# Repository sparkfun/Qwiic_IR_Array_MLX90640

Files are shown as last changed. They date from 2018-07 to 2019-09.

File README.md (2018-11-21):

Qwiic IR Array (MLX90640)
==================

Qwiic IR Array

[*Qwiic IR Array (SEN-14843)*](https://www.sparkfun.com/products/14843)
[*Qwiic IR Array (SEN-14844)*](https://www.sparkfun.com/products/14843)

The MLX90640 contains a 32x24 array of thermopile sensors creating, in essence, a low resolution thermal imaging camera.

Repository Contents
-------------------
* **/Documentation** - Datasheets. 
* **/Firmware** - Examples to use the MLX90640 with a microcontroller.
* **/Hardware** - All Eagle design files (.brd, .sch). 
* **/Production** - Various test jigs and large panel layouts used for production.

Documentation
--------------
* **[Library](https://github.com/sparkfun/SparkFun_MLX90640_Arduino_Example)** - Arduino library for the Qwiic IR Array.
* **[Hookup Guide](https://learn.sparkfun.com/tutorials/qwiic-ir-array-mlx90640-hookup-guide)** - Basic hookup guide for the Qwiic IR Array.

Product Versions
----------------
* [SEN-14843](https://www.sparkfun.com/products/14843)- SparkFun 55 degree FOV
* [SEN-14844](https://www.sparkfun.com/products/14844)- SparkFun 110 degree FOV
* [SPX-14768](https://www.sparkfun.com/products/14768)- SparkX version

License Information
-------------------

The hardware is released under [Creative Commons ShareAlike 4.0 International](https://creativecommons.org/licenses/by-sa/4.0/).
The code is beerware; if you see me (or any other SparkFun employee) at the local, and you've found our code helpful, please buy us a round!

Distributed as-is; no warranty is given.

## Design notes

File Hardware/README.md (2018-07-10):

SparkFun <PRODUCT NAME> Design Files
=====================================

The .sch and .brd files hare are Eagle CAD schematic and PCB design files from SparkFun Electronics.
A freeware version of Eagle can be found [here](http://www.cadsoftusa.com/download-eagle/freeware/).

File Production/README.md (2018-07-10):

SparkFun <PRODUCT NAME> Production Files
=========================================

These are the production files SparkFun uses for printing PCBs.

License Information
-------------------
This product is open source! 

The hardware is released under [Creative Commons ShareAlike 4.0 International](https://creativecommons.org/licenses/by-sa/4.0/).

Please use, reuse, and modify these files as you see fit. Please maintain attribution to SparkFun Electronics and release anything derivative under the same license.

Distributed as-is; no warranty is given.

- Your friends at SparkFun.

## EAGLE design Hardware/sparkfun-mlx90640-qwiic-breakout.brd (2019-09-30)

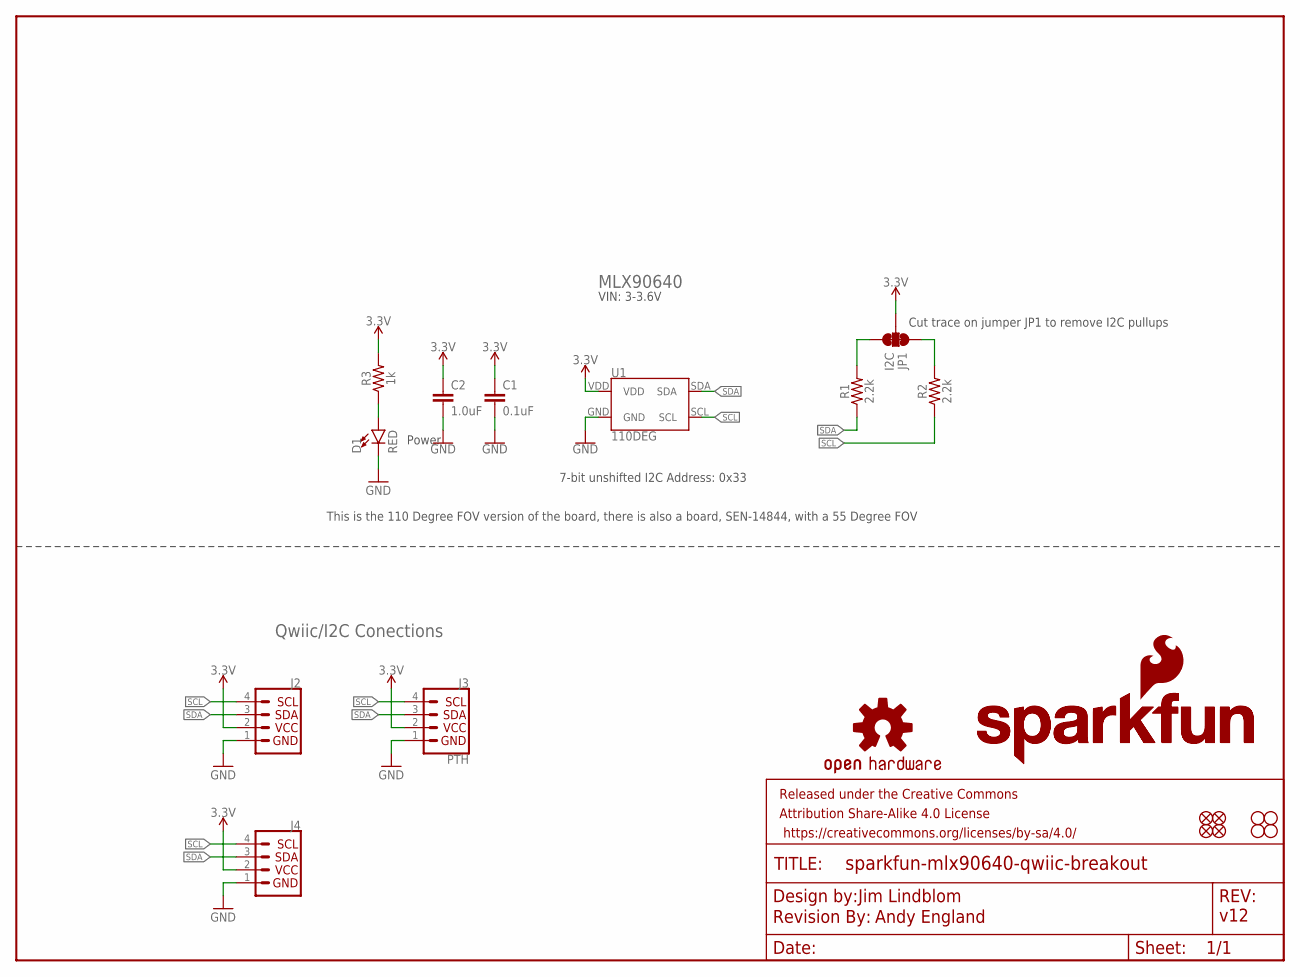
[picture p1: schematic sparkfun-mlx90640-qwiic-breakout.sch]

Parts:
C1: 0.1uF; 0603
C2: 1.0uF; 0603
D1: RED; LED-0603
FRAME1: FRAME-LETTER; CREATIVE_COMMONS
J2, J4: QWIIC_CONNECTORJS-1MM; JST04_1MM_RA
J3: PTH; 1X04_NO_SILK
JP1: I2C; SMT-JUMPER_3_2-NC_TRACE_NO-SILK
JP2, JP5, JP6, JP7: FIDUCIALUFIDUCIAL; MICRO-FIDUCIAL
JP3, JP4, JP8, JP9: STAND-OFF
LOGO1: OSHW-LOGOMINI; OSHW-LOGO-MINI
LOGO2: SFE_LOGO_NAME_FLAME.1_INCH; SFE_LOGO_NAME_FLAME_.1
LOGO3: SFE_LOGO_NAME.1_INCH; SFE_LOGO_NAME_.1
LOGO4: REVISION
R1, R2: 2.2k; 0603
R3: 1k; 0603
U1: 110DEG; MLX90540_MLX90640

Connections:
3.3V: C1.1, C2.1, J2.2, J3.2 (VCC), J4.2, JP1.2, R3.2, U1.VDD
GND: C1.2, C2.2, D1.C, J2.1, J3.1 (GND), J4.1, U1.GND
unnamed: JP1.3, R1.2
unnamed: JP1.1, R2.2
unnamed: D1.A, R3.1
SCL: J2.4, J3.4 (SCL), J4.4, R2.1, U1.SCL
SDA: J2.3, J3.3 (SDA), J4.3, R1.1, U1.SDA

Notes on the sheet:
Power
Jim Lindblom
7-bit unshifted I2C Address: 0x33
v12
Andy England
MLX90640
Qwiic/I2C Conections
VIN: 3-3.6V
This is the 110 Degree FOV version of the board, there is also a board, SEN-14844, with a 55 Degree FOV
Cut trace on jumper JP1 to remove I2C pullups

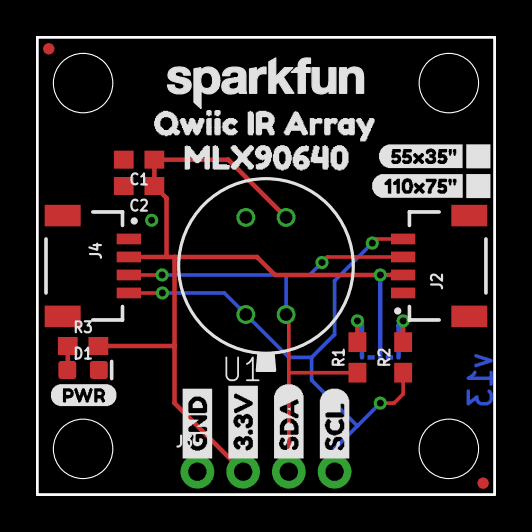
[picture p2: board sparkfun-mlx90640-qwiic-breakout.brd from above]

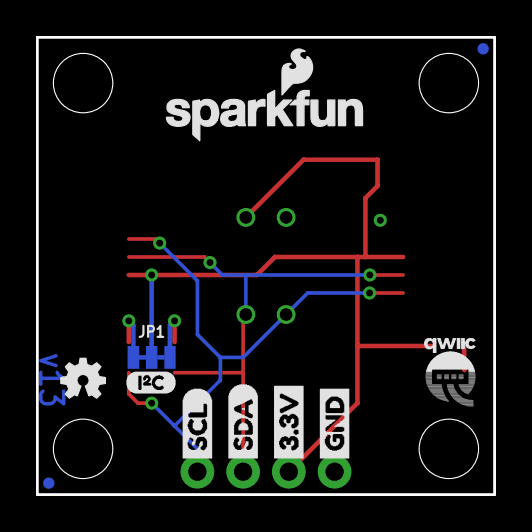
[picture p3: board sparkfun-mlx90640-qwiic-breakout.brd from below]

Board: 2 copper layers, 25.4 x 25.4 mm, 39 parts (11 on the bottom side), 7 nets.

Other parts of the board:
U$1, U$7: SDA-[)
U$3: 55X35#1
U$4, U$8: SCL-[)
U$5, U$9: 3.3V
U$6, U$10: GND-04
U$11: QWIIC-LOGO-SMALL
U$12: PWR-()-03
U$13: MLX906401
U$14: QWIIC_IR_ARRAY0
U$15: 110X75#0
U$16: I_SUPER2_C-()-03

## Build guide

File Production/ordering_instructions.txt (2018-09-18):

panel size, 221x143mm
PCB thickness, 1.6mm
number of layers, 2
soldermask color, Red
silkscreen color, White
oz copper, 1oz
finish, HASL lead free
stencils, none
pcs per panel, 40

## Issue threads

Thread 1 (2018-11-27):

Qwiic_IR_Array_MLX90640 not found by neither i2cdetect nor i2c mulitscanner

namoaton, 2018-11-27:
### Subject of the issue
Qwiic_IR_Array_MLX90640 not found by neither i2cdetect nor i2c mulitscanner
There is a situation when connect scl line on logic analyzer not signal and low level

### Your workbench
* What platform are you using?
raspberry pi 3, linux, and i2 scanner on arduino.
* What version of the device are you using? Is there a firmware version?
last version, which produced in october. wait it for 2 month and now have such problem
* How is the device wired to your platform?
with qwiic connector and directly to pins on rpi3
* How is everything being powered?
from 3.3v pin on rpi3
* Are there any additional details that may help us help you?
I try as with pull up resistors and without them
### Steps to reproduce
Tell us how to reproduce this issue. Please post stripped down example code demonstrating your issue to a gist.
In raspi-config enable i2c support. connect. try to run 'sudo i2cdetect -y 1' and nothing happens.

### Expected behaviour
Tell us what should happen
I expected to get found address 0x33 as described in  manual on Sparkfun site
### Actual behaviour
Tell us what happens instead
Nothing happens. I2cscanner freezes, logic anaylizer is silent, on rpi  silence.

AndyEngland521, 2018-11-27:
This is a small hardware issue that we currently have a fix on order for. The bottom plate of the MLX is ground and on occasion, Solder will flow onto this plate, connecting a signal to ground. My guess is that this is what happened on your SCL signal, and it slipped through our quality control. We have fixed our design to remedy this issue, but it will take a bit of time for this new design to arrive, but give our customer service a call at 1-303-284-0979

Closed 2018-11-27.

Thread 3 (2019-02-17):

"MLX90640 not detected at default I2C address. Please check wiring. Freezing."

ManiLowc, 2019-02-17:
### Subject of the issue
I've downloaded the example code and have been trying to get my sparkfun Qwiic IR Array MLX90640 to work but receive the above error. I have tried the i2c_scanner code to see if my Due was finding the array and it says that an I2C device was found.

When I run the i2c_scanner code my serial port gives:
Scanning...
I2C device found at address 0x0A  !
I2C device found at address 0x13  !
I2C device found at address 0x1A  !
I2C device found at address 0x22  !
I2C device found at address 0x28  !
I2C device found at address 0x2E  !
I2C device found at address 0x34  !
I2C device found at address 0x3A  !
I2C device found at address 0x40  !
I2C device found at address 0x44  !
I2C device found at address 0x48  !
I2C device found at address 0x4C  !
I2C device found at address 0x50  !
I2C device found at address 0x54  !
I2C device found at address 0x57  !
I2C device found at address 0x5B  !
I2C device found at address 0x5F  !
I2C device found at address 0x62  !
I2C device found at address 0x66  !
I2C device found at address 0x6A  !
I2C device found at address 0x6D  !
I2C device found at address 0x71  !
I2C device found at address 0x74  !
I2C device found at address 0x78  !
I2C device found at address 0x7C  !
done

### Your workbench
* What platform are you using?
I'm using the Arduino Due, Qwiic Shield (DEV-14352 ) and Qwiic IR Array MLX90640 (55x35).
* What version of the device are you using? Is there a firmware version?
I'm using the latest Arduino Due, purchased in November 2018. My 'boards manager' and 'library manager' are all up to date with the latest versions.
* How is the device wired to your platform?
I have connected the IR Array with a connector cable to the Qwiic Shield, which is pinned into the Arduino Due. I have the Shield connected to the Due such that A5, IRF, SCL, and RX on the board matches with the Arduino (SCL1 for the arduino) [I've tried attaching a picture as well to make it clearer]

* How is everything being powered?
I have connected the arduino to my pc to be powered.
* Are there any additional details that may help us help you?
I'm a complete novice so sorry for any useless information.

### Steps to reproduce
Tell us how to reproduce this issue. Please post stripped down example code demonstrating your issue to a gist.
I used the code on github, but for the first example I get the error of MLX not detected at default I2C address.

### Expected behaviour
Tell us what should happen
I was expecting the code to run and see values on the serial monitor.

### Actual behaviour
Tell us what happens instead
I get the error MLX90640 not detected at default I2C address.
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

Thank you in advance for any help and it is greatly appreciated!

nseidle, 2019-02-18:
Hi ManiLowc,

I recommend against using a Due. It's I2C implementation has been giving us problems with the ML90640. See this [issue](https://github.com/sparkfun/SparkFun_MLX90640_Arduino_Example/issues/1).

Second possible source of problems: We've had two revisions of this product. If you have the first revision, you may be running into a hardware issue. Can you please post a picture of your MLX90640?

For reference, on the 2nd rev of the board the tab on the sensor has been re-aligned to better line up the pixels of the frame to the orthagonal orientation of the board.

This is rev one:

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

ManiLowc, 2019-02-19:
Hi nseidle,
Thank you for your quick reply. Please find attached a picture of my MLX90640.

For my project, I need a microcontroller with enough computing power that it can use the MLX90640 and encode the thermal data into a language of different frequencies to then be sent to an array of actuators. Would a teensy be best as it would work with the example code? May I ask what microcontroller you would recommend to a novice to use for this project?
Many thanks.
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

nseidle, 2019-02-19:
That is indeed rev one and may be a hardware issue. It's going to be hard to trouble shoot via github. Please contact support@sparkfun.com and they'll get you squared away.

Closed 2019-02-19.

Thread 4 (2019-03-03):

Running into issues with the example code.

ManiLowc, 2019-03-03:
### Subject of the issue
Hello, I'm attempting to use the MLX90640 with the example code generously made available but am running into some issues.

When I compile the Example1_BasicReadings the text below appears in the output window:

Example1_BasicReadings: In function 'void loop()':
Example1_BasicReadings:83: warning: unused variable 'vdd'
     float vdd = MLX90640_GetVdd(mlx90640Frame, &mlx90640);

           ^

Sketch uses 31308 bytes (5%) of program storage space. Maximum is 524288 bytes.
Global variables use 19160 bytes (7%) of dynamic memory, leaving 242976 bytes for local variables. Maximum is 262136 bytes.

I get similar messages when I compile the second and third example code:

Example2_OutputToProcessing: In function 'void loop()':
Example2_OutputToProcessing:81: warning: unused variable 'status'
     int status = MLX90640_GetFrameData(MLX90640_address, mlx90640Frame);

         ^

Example2_OutputToProcessing:83: warning: unused variable 'vdd'
     float vdd = MLX90640_GetVdd(mlx90640Frame, &mlx90640);

           ^

Example2_OutputToProcessing:77: warning: unused variable 'startTime'
   long startTime = millis();

        ^

Example2_OutputToProcessing:91: warning: unused variable 'stopTime'
   long stopTime = millis();

        ^

Sketch uses 31228 bytes (5%) of program storage space. Maximum is 524288 bytes.
Global variables use 19160 bytes (7%) of dynamic memory, leaving 242976 bytes for local variables. Maximum is 262136 bytes.

Example3_MaxRefreshRate: In function 'void loop()':
Example3_MaxRefreshRate:96: warning: unused variable 'status'
     int status = MLX90640_GetFrameData(MLX90640_address, mlx90640Frame);

         ^

Example3_MaxRefreshRate:99: warning: unused variable 'vdd'
     float vdd = MLX90640_GetVdd(mlx90640Frame, &mlx90640);

           ^

Sketch uses 31460 bytes (6%) of program storage space. Maximum is 524288 bytes.
Global variables use 19160 bytes (7%) of dynamic memory, leaving 242976 bytes for local variables. Maximum is 262136 bytes.

The first example seems to work and when I open the serial monitor I see temperatures for 9 pixels.
The second example also seems to work but when I open the Processing code and attempt to run, sometimes I receive the error "ArrayIndexOutOfBoundsException: 87" with the display being completely red, but othertimes it seems to work fine and displays what the camera sees.
When I try to use the third example, I usually get the error "ArrayIndexOutOfBoundsException: xxx" (where xxx are numbers that seems to change) where the display is completely red but sometimes I get "ArrayIndexOutOfBoundsException: 1" where the display at first seems correct but then freezes.
Also when the error appears, the 98th line of code  "if(!Float.isNaN(float(splitString[q])) && float(splitString[q]) > maxTemp){" becomes highlighted.

### Your workbench
* What platform are you using?
I'm using the Teensy 3.5, a breadboard, Qwiic IR Array MLX90640 and qwiic connector cable as recommended on the sparkfun website (please find picture below). I am running the software on my laptop.
* What version of the device are you using? Is there a firmware version?
I'm using Arduino 1.8.8 and the newest Teensyduino downloadable.
* How is the device wired to your platform?
It is connected via USB.
* How is everything being powered?
It is being powered by my laptop.
* Are there any additional details that may help us help you?
I'm a coding novice. I have downloaded the MLX90640 libraries necessary.

### Steps to reproduce
Tell us how to reproduce this issue. Please post stripped down example code demonstrating your issue to a gist.

### Expected behaviour
I expected the display to have a higher refresh rate when using example code 3.

### Actual behaviour
I receive ArrayIndexOutOfBoundsException errors.

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

jamesdanielv, 2019-08-23:
hello, did you get it working yet? i'm not from sparkfun staff, but i'm looking at issues with mlx setup. what is the i2c rate set too? if data rate is too low the getframe routine can not finish its check before the next read. since the mode of data transfer is continueous it needs to at least read all the data in the frame before the time sync of the frame rate. since it reads words then it needs to at least read 834 words x16bits of data) so ~13344 pulses per frame cycle. this means at default 100khz speed of data bus (not sure what it is set to ) reading more than 3 fps (which requires 2 reads per frame cycle) will not allow data to be completely dumped from sensor memory before being overwritten by sensor read. this also can effect status registers for detecting when frame data is ready and have it stuck in a loop where it always is fetching data because the status register always will be indicating new ram values have been written.

if this is your case, then simply increasing data bus speed of i2c will resolve the issue. be careful to keep data wires short, and to only increase incrementally. (maybe 100khz increments) also e sure to keep within spec of mlx controller of 1mhz. if using sparkfun board with 2.2k pullups slew rate should allow higher speeds to work.i would recommend using data bus at about 400khz, and when you know it is stable then increase it from there.

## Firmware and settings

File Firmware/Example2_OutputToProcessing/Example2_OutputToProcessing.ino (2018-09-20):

/*
  Output the temperature readings to all pixels to be read by a Processing visualizer
  By: Nathan Seidle
  SparkFun Electronics
  Date: May 22nd, 2018
  License: MIT. See license file for more information but you can
  basically do whatever you want with this code.

  Feel like supporting open source hardware?
  Buy a board from SparkFun! https://www.sparkfun.com/products/14769

  This example outputs 768 temperature values as fast as possible. Use this example
  in conjunction with our Processing visualizer.

  This example will work with a Teensy 3.1 and above. The MLX90640 requires some
  hefty calculations and larger arrays. You will need a microcontroller with 20,000
  bytes or more of RAM.

  This relies on the driver written by Melexis and can be found at:
  https://github.com/melexis/mlx90640-library

  Hardware Connections:
  Connect the SparkFun Qwiic Breadboard Jumper (https://www.sparkfun.com/products/14425)
  to the Qwiic board
  Connect the male pins to the Teensy. The pinouts can be found here: https://www.pjrc.com/teensy/pinout.html
  Open the serial monitor at 115200 baud to see the output
*/

#include <Wire.h>

#include "MLX90640_API.h"
#include "MLX90640_I2C_Driver.h"

const byte MLX90640_address = 0x33; //Default 7-bit unshifted address of the MLX90640

#define TA_SHIFT 8 //Default shift for MLX90640 in open air

float mlx90640To[768];
paramsMLX90640 mlx90640;

void setup()
{
  Wire.begin();
  Wire.setClock(400000); //Increase I2C clock speed to 400kHz

  Serial.begin(115200); //Fast serial as possible
  
  while (!Serial); //Wait for user to open terminal
  //Serial.println("MLX90640 IR Array Example");

  if (isConnected() == false)
  {
    Serial.println("MLX90640 not detected at default I2C address. Please check wiring. Freezing.");
    while (1);
  }

  //Get device parameters - We only have to do this once
  int status;
  uint16_t eeMLX90640[832];
  status = MLX90640_DumpEE(MLX90640_address, eeMLX90640);
  if (status != 0)
    Serial.println("Failed to load system parameters");

  status = MLX90640_ExtractParameters(eeMLX90640, &mlx90640);
  if (status != 0)
    Serial.println("Parameter extraction failed");

  //Once params are extracted, we can release eeMLX90640 array

  //MLX90640_SetRefreshRate(MLX90640_address, 0x02); //Set rate to 2Hz
  MLX90640_SetRefreshRate(MLX90640_address, 0x03); //Set rate to 4Hz
  //MLX90640_SetRefreshRate(MLX90640_address, 0x07); //Set rate to 64Hz
}

void loop()
{
  long startTime = millis();
  for (byte x = 0 ; x < 2 ; x++)
  {
    uint16_t mlx90640Frame[834];
    int status = MLX90640_GetFrameData(MLX90640_address, mlx90640Frame);

    float vdd = MLX90640_GetVdd(mlx90640Frame, &mlx90640);
    float Ta = MLX90640_GetTa(mlx90640Frame, &mlx90640);

    float tr = Ta - TA_SHIFT; //Reflected temperature based on the sensor ambient temperature
    float emissivity = 0.95;

    MLX90640_CalculateTo(mlx90640Frame, &mlx90640, emissivity, tr, mlx90640To);
  }
  long stopTime = millis();

  for (int x = 0 ; x < 768 ; x++)
  {
    //if(x % 8 == 0) Serial.println();
    Serial.print(mlx90640To[x], 2);
    Serial.print(",");
  }
  Serial.println("");
}

//Returns true if the MLX90640 is detected on the I2C bus
boolean isConnected()
{
  Wire.beginTransmission((uint8_t)MLX90640_address);
  if (Wire.endTransmission() != 0)
    return (false); //Sensor did not ACK
  return (true);
}

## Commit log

2018-07-10 updating to reds
    [sparkfun-mlx90640-qwiic-breakout.brd, sparkfun-mlx90640-qwiic-breakout.sch]
2018-07-17 Post design review changes
    [sparkfun-mlx90640-qwiic-breakout.brd, sparkfun-mlx90640-qwiic-breakout.sch]
2018-07-30 fixing issues
    [sparkfun-mlx90640-qwiic-breakout.brd, sparkfun-mlx90640-qwiic-breakout.sch]
2018-08-03 panel v10 created
    [14043-sparkfun-mlx90640-qwiic-breakout-Panel.brd]
2018-09-18 updating to kit package
    [sparkfun-mlx90640-qwiic-breakout.brd, sparkfun-mlx90640-qwiic-breakout.sch]
2018-11-19 fixing orientation
    [sparkfun-mlx90640-qwiic-breakout.brd, sparkfun-mlx90640-qwiic-breakout.sch]
2018-11-21 Updating silk for single PCB design
    [sparkfun-mlx90640-qwiic-breakout.brd]
2018-11-21 updating readme
    [sparkfun-mlx90640-qwiic-breakout-Panel.GBL, sparkfun-mlx90640-qwiic-breakout-Panel.GBO, sparkfun-mlx90640-qwiic-breakout-Panel.GBS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]
2019-09-30 pulling in PTH holes, needs repanel
    [sparkfun-mlx90640-qwiic-breakout.brd, sparkfun-mlx90640-qwiic-breakout.sch]

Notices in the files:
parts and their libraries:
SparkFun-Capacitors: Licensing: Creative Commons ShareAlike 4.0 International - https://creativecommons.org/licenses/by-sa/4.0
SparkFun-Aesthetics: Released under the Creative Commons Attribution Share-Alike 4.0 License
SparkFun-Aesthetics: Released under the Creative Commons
